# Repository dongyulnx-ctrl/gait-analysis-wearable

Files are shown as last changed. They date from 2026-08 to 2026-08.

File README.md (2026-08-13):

# 基于可穿戴多传感协同判别的步态分析系统

> 一套「可穿戴多传感器采集 → 华为云 OBS → 上位机实时可视化 + CNN-Transformer 步态分类」的端到端系统。

## 项目简介

帕金森病等神经系统疾病的早期诊断中，步态特征是一项关键临床指标。本系统通过可穿戴设备同步采集**双 IMU（惯性测量单元）、双通道 EMG（表面肌电）、双足底压力**三类信号，经 STM32 打包上传至华为云对象存储（OBS），上位机实时拉取并调用深度学习模型，对 **5 类步态**进行在线分类与可视化：

| 编号 | 步态类型 |
|:---:|:---|
| 1 | 正常步态 |
| 2 | 剪刀步态 |
| 3 | 拖曳步态 |
| 4 | 冻结步态 |
| 5 | 慌张步态 |

## 系统架构

```
┌────────────────────┐    无线/串口    ┌──────────────┐    MQTT/HTTP    ┌────────────────┐
│ 可穿戴采集端        │ ──────────────► │  STM32F103   │ ──────────────► │  华为云 OBS     │
│  IMU×2 · EMG×2     │                 │ 数据打包/上传 │                 │  (对象存储)     │
│  足底压力 ADC×2     │                 └──────────────┘                 └───────┬────────┘
└────────────────────┘                                                          │ 实时拉取
                                                                                ▼
                                                                       ┌────────────────┐
                                                                       │  PyQt5 上位机   │
                                                                       │  波形可视化     │
                                                                       │  CNN-Transformer│
                                                                       │  5 类步态分类   │
                                                                       └────────────────┘
```

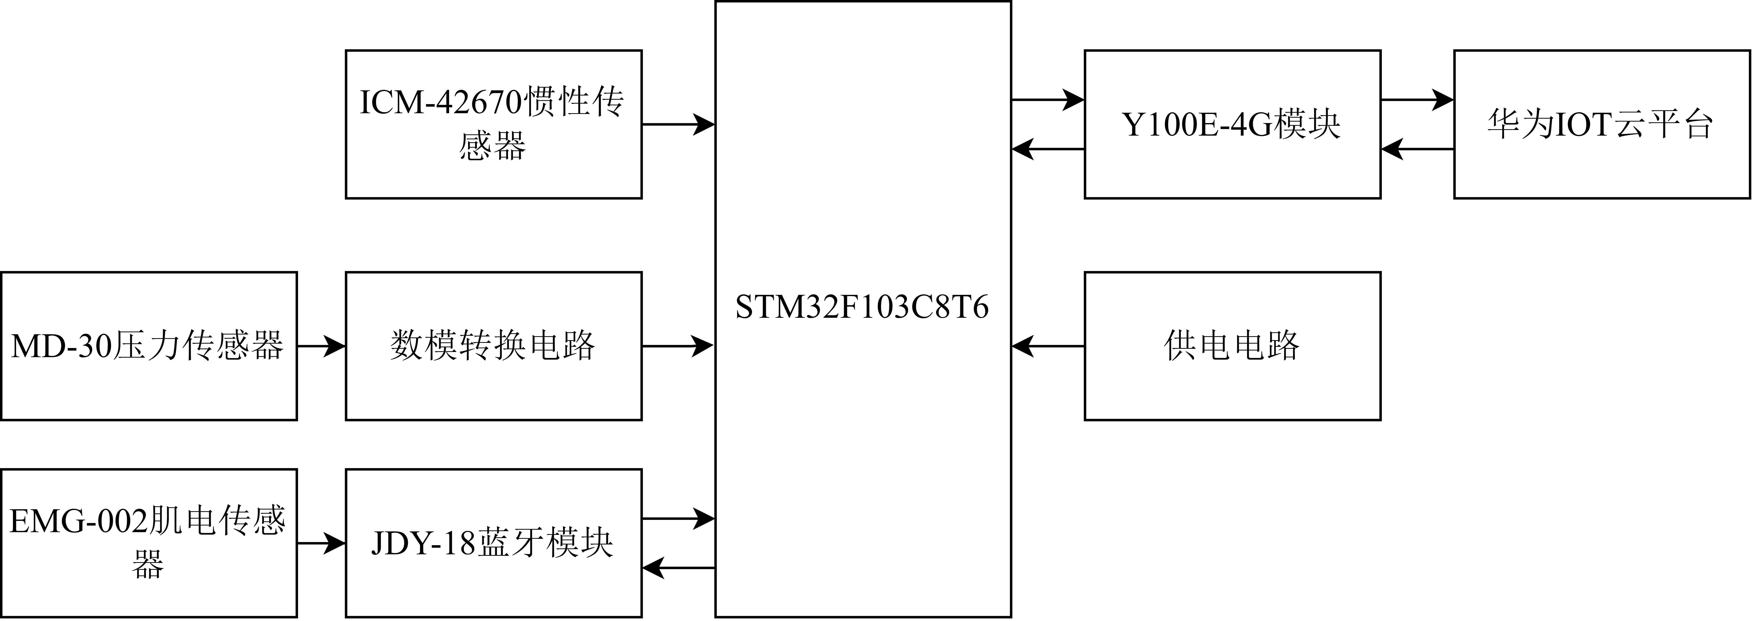
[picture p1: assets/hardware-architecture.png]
硬件框图


## 目录结构

```
gait-analysis-wearable/
├── hardware/
│   ├── embedded/           # STM32F103 嵌入式工程（Keil MDK5）
│   │   └── USART/          #   源码：BSP / CMSIS / FWLib / USER
│   └── PCB/                # 电路设计（Altium + 嘉立创EDA）
│       ├── EMG_V02.SchDoc  #   EMG 采集板原理图
│       ├── EMG_V02.PcbDoc  #   EMG 采集板 PCB
│       ├── *.epro2         #   主板工程（嘉立创EDA）
│       └── BOM_*.xlsx      #   物料清单
├── assets/                 # README 配图
└── software/
    ├── huawei_shwo_v1.7.py   # 上位机主程序（连华为云 OBS 实时接收）
    ├── huawei_show_v仿真.py  # 仿真版（读取本地 CSV 回放，不连云）
    ├── 模型参数/             # 训练好的模型权重 + 归一化参数
    │   ├── best_gait_model_5cls.pth
    │   ├── imu_mean.npy
    │   └── imu_std.npy
    └── 示例数据/             # 仿真版演示用的一段正常步态数据
        └── 2026年5月13日正常步态视频测试.csv
```

## 硬件部分

- **主控**：STM32F103（标准外设库 StdPeriphLib）
- **传感器**：
  - IMU ×2：ICM-42670（六轴陀螺仪 + 加速度计，脚踝 / 足部各一）
  - 磁力计：QMC5883P（姿态解算辅助）
  - EMG ×2：表面肌电采集（蓝左 / 绿右）
  - 足底压力：薄膜压力传感器 ×2（ADC 采集）
- **开发环境**：Keil MDK5，工程入口 `hardware/embedded/USART/USER/USART.uvprojx`

核心代码位于 `USER/`（`main.c`、`fusion_send.c` 数据融合与打包、`emg_feature.c` / `imu_feature.c` 特征提取、`adc.c` 压力采集等）。

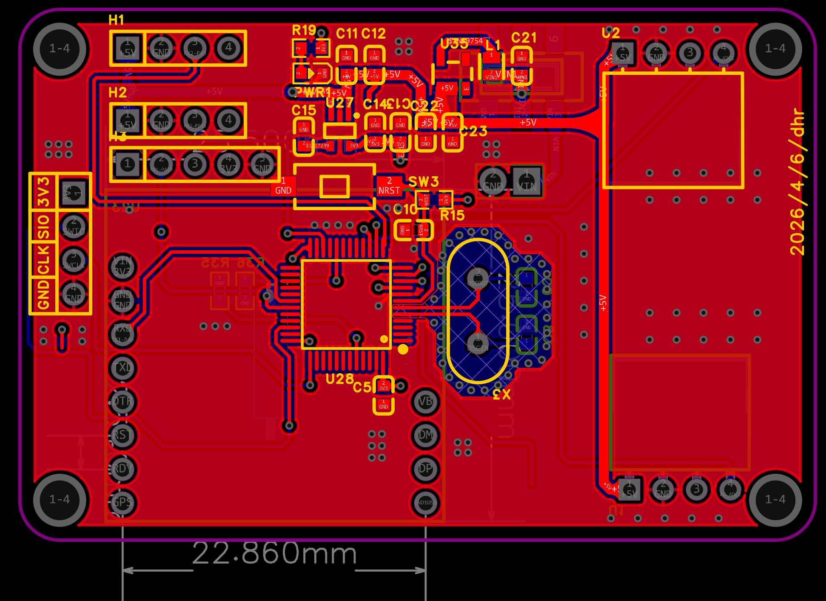
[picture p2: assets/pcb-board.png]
PCB 主板设计


## 软件部分

- **上位机**：PyQt5 + pyqtgraph，多线程架构（OBS 下载线程 / 推理线程 / UI 刷新）
- **云端链路**：华为云 OBS Python SDK（`esdk-obs-python`），实时监听桶内新文件并解析
- **模型**：CNN-Transformer（1D CNN 特征提取 + Transformer Encoder + 全连接分类）

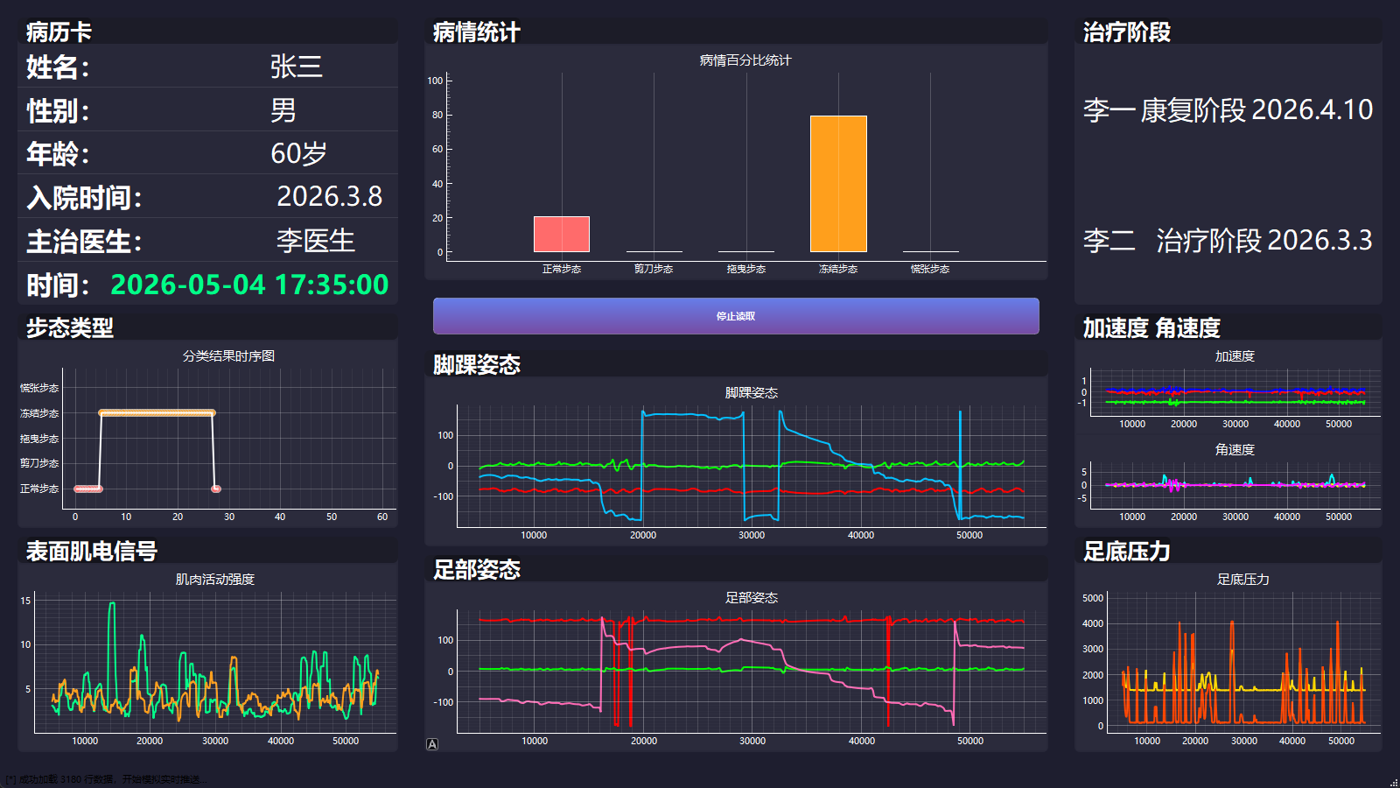
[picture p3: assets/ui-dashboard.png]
上位机界面


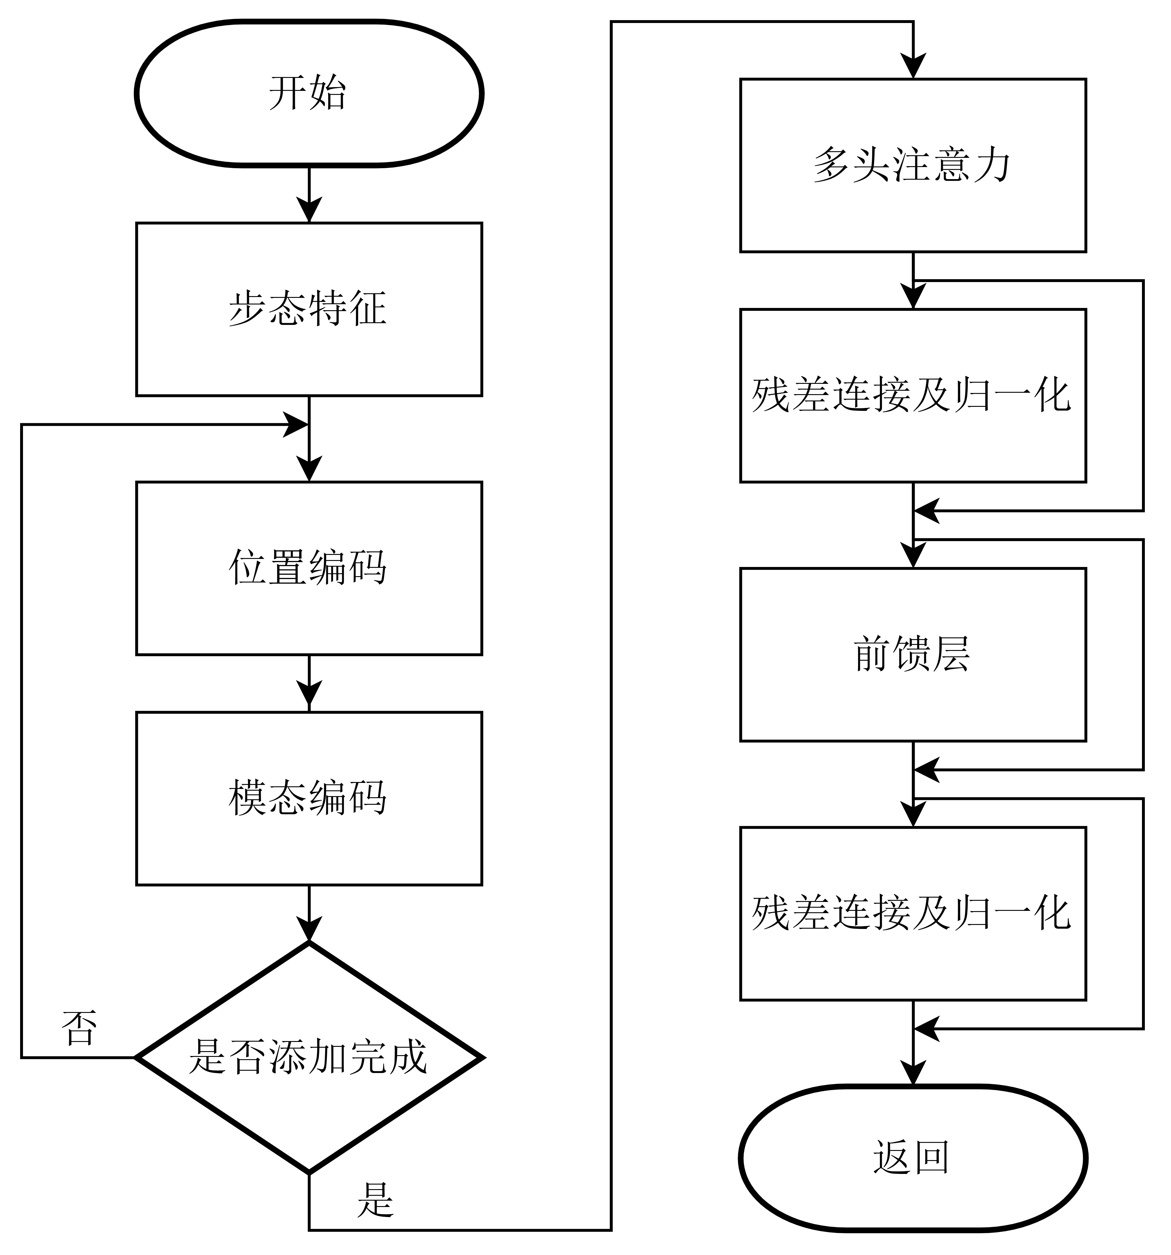
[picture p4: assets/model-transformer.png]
模型结构


## 快速开始

### 依赖安装

```bash
pip install PyQt5 pyqtgraph numpy torch pandas esdk-obs-python
```

### 1. 仿真版（无需云端，最快体验）

```bash
cd software
python huawei_show_v仿真.py
```

脚本会读取 `示例数据/` 下的 CSV，按真实时间戳回放并驱动界面。

### 2. 主程序（连华为云 OBS 实时接收）

1. 编辑 `software/huawei_shwo_v1.7.py`，填入你自己的 OBS 凭证：
   ```python
   AK = "YOUR_ACCESS_KEY".strip()
   SK = "YOUR_SECRET_KEY".strip()
   BUCKET_NAME = "your-bucket-name".strip()
   ```
2. 运行：
   ```bash
   cd software
   python huawei_shwo_v1.7.py
   ```

## 注意事项

- ⚠️ **云凭证请自备**：代码中的 `AK/SK` 已替换为占位符，请填入自己的华为云 OBS 凭证，**切勿将真实密钥提交到公开仓库**。
- 📦 **关于模型**：仓库提供了训练好的权重（`best_gait_model_5cls.pth`）与归一化参数，但**模型结构定义（`model.py`）与训练代码未开源**。如需复现推理，请参考论文自行实现 `cnn_transformer` 结构后再加载权重。
- 模型缺失时，上位机仍可正常启动并展示传感器波形，仅推理功能不可用。

## 开源协议

[MIT License](LICENSE)

## 作者

dongyulnx-ctrl

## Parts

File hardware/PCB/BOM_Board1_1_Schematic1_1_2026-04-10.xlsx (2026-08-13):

No. | Quantity | Comment | Designator | Footprint | Value | Manufacturer Part | Manufacturer | Supplier Part | Supplier
1 | 4 | 104 | C5,C10,C11,C13 | C0603 | 104 | CC0603KRX7R9BB104 | YAGEO(国巨) |  | LCSC
2 | 2 | 20P | C8,C9 | C0603 | 20P | CC0603KRX7R9BB104 | YAGEO(国巨) |  | LCSC
3 | 2 | 105 | C12,C14 | C0603 | 105 | CC0603KRX7R9BB104 | YAGEO(国巨) |  | LCSC
4 | 1 | 223 | C15 | C0603 | 223 | CC0603KRX7R9BB104 | YAGEO(国巨) |  | LCSC
5 | 3 | 10uF | C21,C22,C23 | C0603 | 10uF
6 | 2 | PZ254V-11-04P | H1,H2 | HDR-TH_4P-P2.54-V-M |  | PZ254V-11-04P | XFCN(兴飞) | C2691448 | LCSC
7 | 1 | PZ254V-11-05P | H3 | HDR-TH_5P-P2.54-V-M |  | PZ254V-11-05P | XFCN(兴飞) | C492404 | LCSC
8 | 1 | 2.54-1*4P母 | H8 | HDR-TH_4P-P2.54-V-F |  | 2.54-1*4P母 | BOOMELE(博穆精密) | C2718488 | LCSC
9 | 1 | PZ254V-11-02P | H15 | HDR-TH_2P-P2.54-V-M |  | PZ254V-11-02P | XFCN(兴飞) | C492401 | LCSC
10 | 1 | 4.7uH | L1 | IND-SMD_L2.0-W1.2_FTC201210S | 4.7uH | FTC201210S4R7MBCA | cjiang(长江微电) | C48888268 | LCSC
11 | 1 | LED_0603-R | PWR1 | LED_0603
12 | 3 | 10K | R15,R35,R36 | R0603 | 10K
13 | 1 | 4k7 | R19 | R0603 | 4k7
14 | 1 | TS-1101-C-W | SW3 | SW-SMD_L6.0-W3.3-LS8.0 |  | TS-1101-C-W | XKB Connectivity(中国星坤) | C318938 | LCSC
15 | 2 | DW254W-11-04-85 | U1,U2 | HDR-TH_4P-P2.54-H-F-W10.3-N |  | DW254W-11-04-85 | DEALON(德艺隆) | C2935994 | LCSC
16 | 1 | SW1 | U17 | SW-SMD_MST22D18G2 |  | SW1 | hanxia(韩下) | C5149822 | LCSC
17 | 1 | 4G_M780E | U23 | 4G_M780E
18 | 1 | ME6211C33R5G | U27 | SOT-353_L2.1-W1.3-P0.65-LS2.3-BL |  | ME6211C33R5G | MICRONE(南京微盟) | C235316 | LCSC
19 | 1 | STM32F103C8T6 | U28 | LQFP-48_L7.0-W7.0-P0.50-LS9.0-BL |  | STM32F103C8T6 | ST(意法半导体) | C8734 | LCSC
20 | 1 | PW5100 | U35 | SOT-23-5_L2.9-W1.6-P0.95-LS2.8-BL |  | PW5100 |  | C9900000624 | LCSC
21 | 1 | 8MHz | X3 | OSC-TH_L10.0-W4.5-P5.00 | 8MHz | X49SD8MSD2SC | YXC(扬兴晶振) | C21263 | LCSC

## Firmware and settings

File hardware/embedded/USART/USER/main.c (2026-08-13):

#include "AllHeader.h"
#include "imu_uart_driver.h"
#include "imu_feature.h"
#include "emg_feature.h"
#include "fusion_send.h"
#include "adc.h"  /* 添加：包含ADC头文件 */
#include <stdio.h>

/* 定义两个 IMU 数据结构体 */
imu_measurement_t imu1_data;
imu_measurement_t imu2_data;


/* 定义两个 ADC 原始值变量 */
uint16_t adc1_value; /* PA4 */
uint16_t adc2_value; /* PA5 */

/* 100ms 发送标志 */
extern volatile uint8_t send_flag;

int main(void)
{
    bsp_init();
    
    /* 初始化定时器 */
    TIM3_Init(); 


    /* 初始化两个 IMU */
    printf("Initializing IMUs...\r\n");
    IMU_UART_Init(IMU_INSTANCE_1);
    IMU_UART_Init(IMU_INSTANCE_2);
    
    /* 初始化 EMG */
    printf("Initializing EMG...\r\n");
    EMG_UART_Init();
	
	   printf("Initializing ADC...\r\n");
    Adc_Config(); 
    
    /* 初始化 Raw 数据模块 */
    IMU_Raw_Init();
    EMG_Raw_Init();

    /* 获取 IMU 版本号 */
    printf("Reading IMU Versions...\r\n");
    IMU_UART_GetVersion(IMU_INSTANCE_1);
    IMU_UART_GetVersion(IMU_INSTANCE_2);

    printf("System Ready! Starting Data Fusion...\r\n");

    while(1)
    {
        /* 1. 解析 IMU 和 EMG */
        IMU_UART_Process(IMU_INSTANCE_1);
        IMU_UART_Process(IMU_INSTANCE_2);
        EMG_UART_Process();

        /* 2. 获取 IMU 数据 */
        IMU_UART_GetAll(IMU_INSTANCE_1, &imu1_data);
        IMU_UART_GetAll(IMU_INSTANCE_2, &imu2_data);

				Get_Two_ADC_Values(&adc1_value, &adc2_value);

        /* 4. 更新 Raw 数据 */
        IMU_Raw_Update(&imu1_data, &imu2_data);

        /* 5. 100ms 发送 */
        if(send_flag)
        {
            Fusion_Send_Update(adc1_value, adc2_value); /* 修改：传入ADC值 */
        }
    }
}

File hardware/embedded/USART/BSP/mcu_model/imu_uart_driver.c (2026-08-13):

#include "imu_uart_driver.h"
#include <stdio.h>
#include <string.h>
#include <math.h>

static const ImuHwConfig hw_configs[IMU_INSTANCE_MAX] = {
    /* IMU_INSTANCE_1: UART2, PA2(TX), PA3(RX) */
    {
        .usart = USART2,
        .tx_gpio_port = GPIOA,
        .tx_gpio_pin = GPIO_Pin_2,
        .rx_gpio_port = GPIOA,
        .rx_gpio_pin = GPIO_Pin_3,
        .rcc_apb2_gpio = RCC_APB2Periph_GPIOA,
        .rcc_apb1_usart = RCC_APB1Periph_USART2,
        .irqn = USART2_IRQn,
        .irq_preemption_priority = 1,  // 不变
        .irq_sub_priority = 0          // 改 0
    },
    /* IMU_INSTANCE_2: UART3, PB10(TX), PB11(RX) */
    {
        .usart = USART3,
        .tx_gpio_port = GPIOB,
        .tx_gpio_pin = GPIO_Pin_10,
        .rx_gpio_port = GPIOB,
        .rx_gpio_pin = GPIO_Pin_11,
        .rcc_apb2_gpio = RCC_APB2Periph_GPIOB,
        .rcc_apb1_usart = RCC_APB1Periph_USART3,
        .irqn = USART3_IRQn,
        .irq_preemption_priority = 2,  // 改 2
        .irq_sub_priority = 0          // 改 0
    }
};

/* ---------------- IMU 句柄实例 ---------------- */
ImuHandle imu_handles[IMU_INSTANCE_MAX] = {0};

/* ---------------- 内部辅助宏/函数 (操作句柄内的环形缓冲) ---------------- */
static inline uint16_t _rxbuf_next(ImuHandle* handle, uint16_t index)
{
    return (uint16_t)((index + 1u) % IMU_UART_RX_BUF_SIZE);
}

static inline int _rxbuf_is_empty(ImuHandle* handle)
{
    return handle->rx_write_index == handle->rx_read_index;
}

static inline void _rxbuf_push(ImuHandle* handle, uint8_t byte_value)
{
    uint16_t next_index = _rxbuf_next(handle, handle->rx_write_index);
    if (next_index == handle->rx_read_index) {
        handle->rx_read_index = _rxbuf_next(handle, handle->rx_read_index);
    }
    handle->rx_buffer[handle->rx_write_index] = byte_value;
    handle->rx_write_index = next_index;
}

static inline int _rxbuf_pop(ImuHandle* handle, uint8_t *out_byte)
{
    if (_rxbuf_is_empty(handle)) {
        return -1;
    }
    *out_byte = handle->rx_buffer[handle->rx_read_index];
    handle->rx_read_index = _rxbuf_next(handle, handle->rx_read_index);
    return 0;
}

/** 将两个字节转换为 int16 */
static int16_t to_int16(const uint8_t *bytes)
{
    return (int16_t)((bytes[1] << 8) + bytes[0]);
}

/** 将四个字节转换为 float */
static float to_float(const uint8_t *bytes)
{
    float v;
    memcpy(&v, bytes, sizeof(float));
    return v;
}

/* ---------------- 解析数据帧 (操作指定句柄) ---------------- */
static void _parse_frame_data(ImuHandle* handle, uint8_t frame_function, const uint8_t *frame_data)
{
    if (frame_function == IMU_FUNC_RAW_ACCEL) {
        float accel_ratio = 16.0f / 32767.0f;
        handle->ax = to_int16(&frame_data[0])  * accel_ratio;
        handle->ay = to_int16(&frame_data[2])  * accel_ratio;
        handle->az = to_int16(&frame_data[4])  * accel_ratio;

        float deg_to_rad = 3.14159265358979323846f / 180.0f;
        float gyro_ratio  = (2000.0f / 32767.0f) * deg_to_rad;
        handle->gx = to_int16(&frame_data[6])  * gyro_ratio;
        handle->gy = to_int16(&frame_data[8])  * gyro_ratio;
        handle->gz = to_int16(&frame_data[10]) * gyro_ratio;

        float mag_ratio = 800.0f / 32767.0f;
        handle->mx = to_int16(&frame_data[12]) * mag_ratio;
        handle->my = to_int16(&frame_data[14]) * mag_ratio;
        handle->mz = to_int16(&frame_data[16]) * mag_ratio;
    } else if (frame_function == IMU_FUNC_EULER) {
        handle->roll  = to_float(&frame_data[0]);
        handle->pitch = to_float(&frame_data[4]);
        handle->yaw   = to_float(&frame_data[8]);
    } else if (frame_function == IMU_FUNC_QUAT) {
        handle->q0 = to_float(&frame_data[0]);
        handle->q1 = to_float(&frame_data[4]);
        handle->q2 = to_float(&frame_data[8]);
        handle->q3 = to_float(&frame_data[12]);
    } else if (frame_function == IMU_FUNC_BARO) {
        handle->height            = to_float(&frame_data[0]);
        handle->temperature       = to_float(&frame_data[4]);
        handle->pressure          = to_float(&frame_data[8]);
        handle->pressure_contrast = to_float(&frame_data[12]);
    } else if (frame_function == IMU_FUNC_VERSION) {
        handle->version_high = frame_data[0];
        handle->version_mid  = frame_data[1];
        handle->version_low  = frame_data[2];
    } else if (frame_function == IMU_FUNC_RETURN_STATE) {
        handle->last_rx_function = frame_data[0];
        handle->last_rx_state    = (int16_t)frame_data[1];
    }
}

/* ---------------- 初始化接口 ---------------- */
void IMU_UART_Init(ImuInstance id)
{
    if (id >= IMU_INSTANCE_MAX) return;
    
    ImuHandle* handle = &imu_handles[id];
    const ImuHwConfig* hw = &hw_configs[id];
    
    /* 关联硬件配置 */
    handle->hw_config = hw;
    
    /* 初始化句柄内的状态变量 */
    handle->rx_write_index = 0;
    handle->rx_read_index = 0;
    handle->rx_state = 0;
    handle->frame_length = 0;
    handle->frame_function = 0;
    handle->frame_index = 0;
    handle->version_high = -1;
    handle->imu_cache_index = 0;
    handle->imu_cache_full = 0;
    IMU_UART_ClearAutoReportData(id);

    GPIO_InitTypeDef GPIO_InitStructure;
    USART_InitTypeDef USART_InitStructure;
    NVIC_InitTypeDef NVIC_InitStructure;

    /* 打开 GPIO 时钟 */
    RCC_APB2PeriphClockCmd(hw->rcc_apb2_gpio, ENABLE);

    /* 打开 USART 时钟 (UART2/3 在 APB1) */
    RCC_APB1PeriphClockCmd(hw->rcc_apb1_usart, ENABLE);

    /* 配置 TX 引脚为推挽复用模式 */
    GPIO_InitStructure.GPIO_Pin = hw->tx_gpio_pin;
    GPIO_InitStructure.GPIO_Mode = GPIO_Mode_AF_PP;
    GPIO_InitStructure.GPIO_Speed = GPIO_Speed_50MHz;
    GPIO_Init(hw->tx_gpio_port, &GPIO_InitStructure);

    /* 配置 RX 引脚为浮空输入模式 */
    GPIO_InitStructure.GPIO_Pin = hw->rx_gpio_pin;
    GPIO_InitStructure.GPIO_Mode = GPIO_Mode_IN_FLOATING;
    GPIO_Init(hw->rx_gpio_port, &GPIO_InitStructure);

    /* NVIC 配置 */
    NVIC_InitStructure.NVIC_IRQChannel = hw->irqn;
    NVIC_InitStructure.NVIC_IRQChannelPreemptionPriority = hw->irq_preemption_priority;
    NVIC_InitStructure.NVIC_IRQChannelSubPriority = hw->irq_sub_priority;
    NVIC_InitStructure.NVIC_IRQChannelCmd = ENABLE;
    NVIC_Init(&NVIC_InitStructure);

    /* USART 配置 */
    USART_InitStructure.USART_BaudRate = 115200;
    USART_InitStructure.USART_WordLength = USART_WordLength_8b;
    USART_InitStructure.USART_StopBits = USART_StopBits_1;
    USART_InitStructure.USART_Parity = USART_Parity_No;
    USART_InitStructure.USART_HardwareFlowControl = USART_HardwareFlowControl_None;
    USART_InitStructure.USART_Mode = USART_Mode_Rx | USART_Mode_Tx;
    USART_Init(hw->usart, &USART_InitStructure);

    /* 开启接收中断 */
    USART_ITConfig(hw->usart, USART_IT_RXNE, ENABLE);
    USART_Cmd(hw->usart, ENABLE);
}

/* ---------------- 中断接收入口 ---------------- */
void IMU_UART_RxBytes(ImuInstance id, volatile uint8_t *data, uint16_t len)
{
    if (id >= IMU_INSTANCE_MAX || !data || len == 0) return;
    ImuHandle* handle = &imu_handles[id];
    
    for (uint16_t i = 0; i < len; ++i) {
        _rxbuf_push(handle, data[i]);
    }
}
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

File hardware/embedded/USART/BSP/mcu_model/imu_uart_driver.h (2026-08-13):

#ifndef IMU_UART_DRIVER_H
#define IMU_UART_DRIVER_H

#include <stdint.h>
#include "delay.h"
#include "usart.h"

/* 配置项 / Config */
#ifndef IMU_UART_RX_BUF_SIZE
#define IMU_UART_RX_BUF_SIZE 256  /* 环形接收缓冲区大小 / RX ring buffer size */
#endif

#define FRAME_HEAD1 0x7E
#define FRAME_HEAD2 0x23

/* 功能码 / Function codes */
#define IMU_FUNC_VERSION        0x01
#define IMU_FUNC_RAW_ACCEL      0x04
#define IMU_FUNC_RAW_GYRO       0x0A
#define IMU_FUNC_RAW_MAG        0x10
#define IMU_FUNC_QUAT           0x16
#define IMU_FUNC_EULER          0x26
#define IMU_FUNC_BARO           0x32
#define IMU_FUNC_CALIB_IMU      0x70
#define IMU_FUNC_CALIB_MAG      0x71
#define IMU_FUNC_CALIB_BARO     0x72
#define IMU_FUNC_CALIB_TEMP     0x73
#define IMU_FUNC_REQUEST_DATA   0x80
#define IMU_FUNC_RETURN_STATE   0x81
#define IMU_FUNC_RESET_FLASH    0xA0

/* IMU 实例枚举 / IMU Instance Enumeration */
typedef enum {
    IMU_INSTANCE_1 = 0,  /* 使用 UART2 (PA2/PA3) */
    IMU_INSTANCE_2 = 1,  /* 使用 UART3 (PB10/PB11) */
    IMU_INSTANCE_MAX
} ImuInstance;

/* 结构体：一次性获取所有传感器数据 / Struct: get all sensor data at once */
typedef struct {
    float accel[3];
    float gyro[3];
    float mag[3];
    float quat[4];
    float euler[3];
    float baro[4];
    char  version[8];
} imu_measurement_t;

/* IMU 缓存数据结构 */
#define IMU_CACHE_SIZE 20
typedef struct {
    float pitch;
    float roll;
    float yaw;
} IMU_CACHE_DATA;

/* IMU 硬件配置结构 / IMU Hardware Configuration Structure */
typedef struct {
    USART_TypeDef* usart;           /* USART 外设指针 */
    GPIO_TypeDef*  tx_gpio_port;    /* TX 引脚 GPIO 端口 */
    uint16_t       tx_gpio_pin;     /* TX 引脚编号 */
    GPIO_TypeDef*  rx_gpio_port;    /* RX 引脚 GPIO 端口 */
    uint16_t       rx_gpio_pin;     /* RX 引脚编号 */
    uint32_t       rcc_apb2_gpio;   /* GPIO 时钟 (RCC_APB2Periph_...) */
    uint32_t       rcc_apb1_usart;  /* USART 时钟 (RCC_APB1Periph_...) */
    IRQn_Type      irqn;             /* 中断向量号 */
    uint8_t        irq_preemption_priority; /* 中断抢占优先级 */
    uint8_t        irq_sub_priority;        /* 中断子优先级 */
} ImuHwConfig;

/* IMU 句柄结构 / IMU Handle Structure (封装所有实例相关状态) */
typedef struct {
    /* 硬件配置 */
    const ImuHwConfig* hw_config;
    
    /* 环形缓冲 / RX ring buffer */
    volatile uint8_t  rx_buffer[IMU_UART_RX_BUF_SIZE];
    volatile uint16_t rx_write_index;
    volatile uint16_t rx_read_index;
    
    /* 解析状态机 / Parse state machine */
    uint8_t  rx_state;
    uint8_t  frame_length;
    uint8_t  frame_function;
    uint8_t  frame_buffer[64];
    uint16_t frame_index;
    
    /* 内部缓存数据 / Internal cached state */
    volatile float ax, ay, az;
    volatile float gx, gy, gz;
    volatile float mx, my, mz;
    volatile float roll, pitch, yaw;
    volatile float q0, q1, q2, q3;
    volatile float height, temperature, pressure, pressure_contrast;
    volatile int   version_high, version_mid, version_low;
    volatile uint8_t last_rx_function;
    volatile int16_t last_rx_state;
    
    /* IMU 缓存 / IMU Cache */
    IMU_CACHE_DATA imu_cache[IMU_CACHE_SIZE];
    volatile uint8_t imu_cache_index;
    volatile uint8_t imu_cache_full;
} ImuHandle;

/* 外部声明 IMU 句柄 / External IMU Handles */
extern ImuHandle imu_handles[IMU_INSTANCE_MAX];

/* ---------------- 函数接口 (所有接口增加 ImuInstance 参数) ---------------- */

/**
 * @brief 初始化指定 IMU 实例
 * @param id IMU 实例编号 (IMU_INSTANCE_1 或 IMU_INSTANCE_2)
 */
void IMU_UART_Init(ImuInstance id);

/**
 * @brief 中断接收入口，将新数据写入环形缓冲
 * @param id IMU 实例编号
 * @param data 接收数据指针
 * @param len 数据长度
 */
void IMU_UART_RxBytes(ImuInstance id, volatile uint8_t *data, uint16_t len);

/**
 * @brief 解析环形缓冲中的数据，提取完整帧并更新缓存
 * @param id IMU 实例编号
 */
void IMU_UART_Process(ImuInstance id);

/**
 * @brief 发送命令到指定 IMU
 * @param id IMU 实例编号
 * @param function 功能码
 * @param params 参数指针
 * @param param_len 参数长度
 * @return 0 成功, -1 失败
 */
int IMU_UART_SendCommand(ImuInstance id, uint8_t function, const uint8_t *params, uint8_t param_len);

/**
 * @brief 清理缓存数据
 * @param id IMU 实例编号
 */
void IMU_UART_ClearAutoReportData(ImuInstance id);

/* 数据读取接口 (均增加 ImuInstance 参数) */
int IMU_UART_GetAccelerometer(ImuInstance id, float out[3]);
int IMU_UART_GetGyroscope(ImuInstance id, float out[3]);
int IMU_UART_GetMagnetometer(ImuInstance id, float out[3]);
int IMU_UART_GetQuaternion(ImuInstance id, float out[4]);
int IMU_UART_GetEuler(ImuInstance id, float out[3]);
int IMU_UART_GetBarometer(ImuInstance id, float out[4]);
void IMU_UART_GetVersion(ImuInstance id);
int IMU_UART_GetAll(ImuInstance id, imu_measurement_t *out);

/* 发送函数 (增加 ImuInstance 参数) */
void Send_IMU_Data(ImuInstance id, uint8_t Data);
void Send_IMU_Array(ImuInstance id, uint8_t *pData, uint8_t Length);

/* 校准 API (增加 ImuInstance 参数) */
int IMU_UART_CalibrationImu(ImuInstance id);
int IMU_UART_CalibrationMag(ImuInstance id);
int IMU_UART_CalibrationTemp(ImuInstance id, float now_temperature);
int IMU_UART_ResetUserData(ImuInstance id);
int IMU_UART_WaitCalibration(ImuInstance id, uint8_t function, uint32_t timeout_ms);

/* IMU 缓存操作 (增加 ImuInstance 参数) */
void IMU_Buffer_Push(ImuInstance id);

/* 中断处理函数声明 */
void USART2_IRQHandler(void); /* IMU_INSTANCE_1 中断 */
void USART3_IRQHandler(void); /* IMU_INSTANCE_2 中断 */

#endif /* IMU_UART_DRIVER_H */

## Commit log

2026-08-13 Initial commit: wearable multi-sensor gait analysis system
    STM32F103 multi-sensor acquisition + Huawei Cloud OBS + PyQt5 real-time
    visualization + CNN-Transformer 5-class gait classification.
    [2026年5月13日正常步态视频测试.csv, BOM_Board1_1_Schematic1_1_2026-04-10.xlsx, EMG_V02.SchDoc]
2026-08-13 chore: remove real name from PCB project filename
